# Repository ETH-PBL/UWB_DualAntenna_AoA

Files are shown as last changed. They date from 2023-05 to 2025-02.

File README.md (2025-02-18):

<!--
*** Template source: https://github.com/othneildrew/Best-README-Template/blob/master/README.md
-->

<!-- PROJECT SHIELDS -->
<!--
*** I'm using markdown "reference style" links for readability.
*** Reference links are enclosed in brackets [ ] instead of parentheses ( ).
*** See the bottom of this document for the declaration of the reference variables
*** for contributors-url, forks-url, etc. This is an optional, concise syntax you may use.
*** https://www.markdownguide.org/basic-syntax/#reference-style-links
-->
[][contributors-url]
[][forks-url]
[][stars-url]
[][issues-url]
[][license-url]

# Angle of Arrival and Centimeter Distance Estimation with a miniaturized UWB Module

This repository contains the hardware of an UWB-AoA shield using the Qorvo DW3220 and presented in ***Angle of arrival and centimeter distance estimation on a smart UWB sensor node***. 
Additionally the repository contains firmware to use the module with an STM32 and dataset as presented in the publication. An in-depth analysis of  the hardware and the proposed algorithms for error compensation and angle estimation can be found here: 
[IEEE TIM](https://doi.org/10.1109/TIM.2023.3282289) / [arXiv:2312.13672 (preprint)](https://doi.org/10.48550/arXiv.2312.13672)

> <div align="justify">Accurate and low-power indoor localization is becoming more and more of a necessity to empower novel consumer and industrial applications. In this field, the most promising technology is based on UWB modulation; however, current UWB positioning systems do not reach centimeter accuracy in general deployments due to multipath and nonisotropic antennas, still necessitating several fixed anchors to estimate an object's position in space. This article presents an in-depth study and assessment of angle of arrival (AoA) UWB measurements using a compact, low-power solution integrating a novel commercial module with phase difference of arrival (PDoA) estimation as integrated feature. Results demonstrate the possibility of reaching centimeter distance precision and 2.4° average angular accuracy in many operative conditions, e.g., in a 90° range around the center. Moreover, integrating the channel impulse response, the phase differential of arrival, and the point-to-point distance, an error correction model is discussed to compensate for reflections, multipaths, and front-back ambiguity.</div>

If you use **Angle of Arrival and Centimeter Distance Estimation with a miniaturized UWB Module** in an academic or industrial context, please cite the following publications:

```bibtex
@article{margiani2023angle,
  title={Angle of arrival and centimeter distance estimation on a smart UWB sensor node},
  author={Margiani, Tobias and Cortesi, Silvano and Keller, Milena and Vogt, Christian and Polonelli, Tommaso and Magno, Michele},
  journal={IEEE Transactions on Instrumentation and Measurement},
  doi={https://doi.org/10.1109/TIM.2023.3282289},
  year={2023},
  publisher={IEEE}
}
```

```bibtex
@inproceedings{polonelli2022performance,
  title={Performance Comparison between Decawave DW1000 and DW3000 in low-power double side ranging applications},
  author={Polonelli, Tommaso and Schl{\"a}pfer, Simon and Magno, Michele},
  booktitle={2022 IEEE Sensors Applications Symposium (SAS)},
  doi={https://doi.org/10.1109/SAS54819.2022.9881375},
  pages={1--6},
  year={2022},
  organization={IEEE}
}
```
## Folder structure

The hardware design files are located in [Hardware](Hardware).

The published data and ML models are available in the [Dataset](Dataset) subfolder.

The firmware used for the double antenna and single antenna modules is
available in the [Firmware](Firmware) subfolder.

Each folder contains a `README.md` containing more information.

### Hardware - UWB Modules

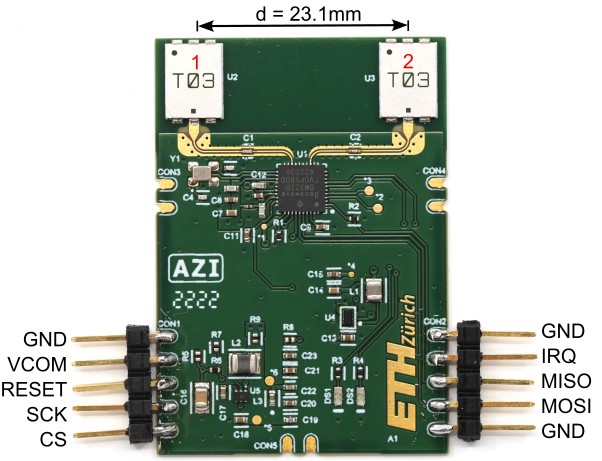
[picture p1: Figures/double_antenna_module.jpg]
Double Antenna Module


We release two modules,
- [T_Module](Hardware/T_module) (22x28 mm) optimized for production cost and dimensions
- [UWB_AoA_module](Hardware/UWB_AoA_module) (30x45 mm) optimized for performances and R&D
   Used for the scientific publication "Angle of arrival and centimeter distance estimation on a smart UWB sensor node"

### Firmware

The firmware consists of basic applications using the Qorvo SDK on an STM32. The created applications read PDoA and CIR values from the UWB module, and transmit them to the computer using UART.

### Dataset

The data contains records from more than 19000 Two Way Ranging (TWR) exchanges
and is collected at the double antenna module. Raw data containing
measurements from each received UWB frame as well as preprocessed data with a
subset of fields from TWR result frames is provided. The training script of two different lightweight ML models is also provided. 

### Scripts

The double antenna UWB module sends measurement data over the serial connection for processing. The scripts in this directory help to save and preprocess that data for analysis.

[contributors-shield]: https://img.shields.io/github/contributors/ETH-PBL/UWB_DualAntenna_AoA.svg?style=flat-square
[contributors-url]: https://github.com/ETH-PBL/UWB_DualAntenna_AoA/graphs/contributors
[forks-shield]: https://img.shields.io/github/forks/ETH-PBL/UWB_DualAntenna_AoA.svg?style=flat-square
[forks-url]: https://github.com/ETH-PBL/UWB_DualAntenna_AoA/network/members
[stars-shield]: https://img.shields.io/github/stars/ETH-PBL/UWB_DualAntenna_AoA.svg?style=flat-square
[stars-url]: https://github.com/ETH-PBL/UWB_DualAntenna_AoA/stargazers
[issues-shield]: https://img.shields.io/github/issues/ETH-PBL/UWB_DualAntenna_AoA.svg?style=flat-square
[issues-url]: https://github.com/ETH-PBL/UWB_DualAntenna_AoA/issues
[license-shield]: https://img.shields.io/github/license/ETH-PBL/UWB_DualAntenna_AoA.svg?style=flat-square
[license-url]: https://github.com/ETH-PBL/UWB_DualAntenna_AoA/blob/master/LICENSE

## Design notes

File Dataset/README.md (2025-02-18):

# Measurement Data

This folder contains two sets of measurement data. First, a dataset to
evaluate the performance of the DW3220 at different distances and roations
("rotation" dataset) and second, a dataset to evaluate the stability of the
measurements over time ("stability" dataset).

## Data collection setup

For all measurements one single antenna module and one double antenna module
was set up in an 8.6m x 7.7m room containing tables and office equipment
placed along the walls and a 6.5m x 5.5m empty space where the measurements
were performed. The single antenna module was fixed on a tripod at a height of
1.1m. The double antenna module was mounted on a rotatable motorized platform
at the same height, providing the ground truth AoA.

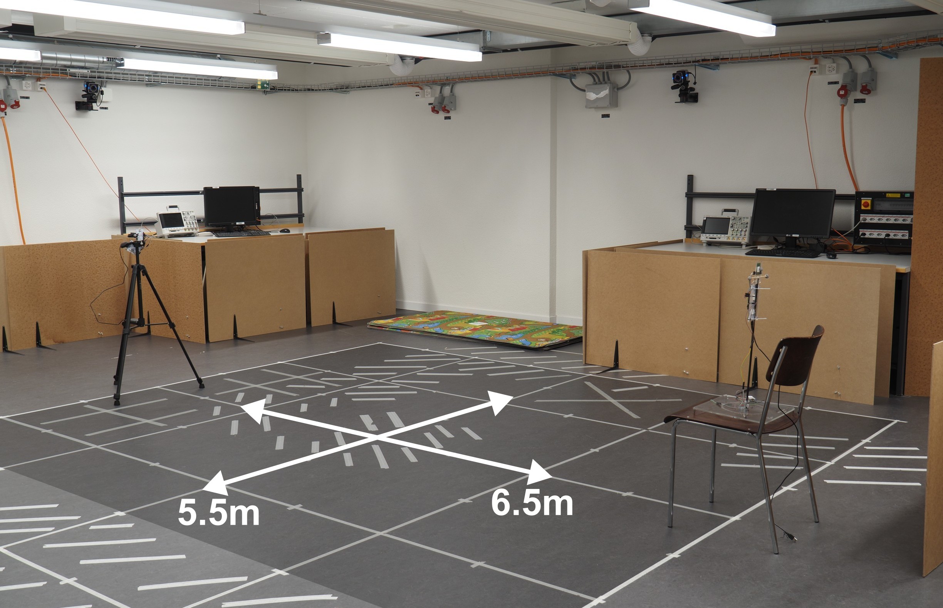
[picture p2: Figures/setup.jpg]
Recording Setup


### Rotation dataset

Data collected at 11 fixed distances ranging from 50cm to 5.5m in 50cm
steps. At each distance, the double antenna module was automatically rotated
in 1 degree steps for a full rotation. At least five TWR measurements were
performed in each position/rotation. Each measurement run contains data for a
single distance and all rotations.

### Stability dataset

Data collected at a fixed distance of 5.4m and with 0, 90, 180, and 270 degree
AoA. Approximately 3000 frames are collected over a period of 11 minutes with
no movement in the room. Each measurement run contains data at a fixed
distance and rotation.

## Data format

The data provided in the two subfolders is based on the same
measurements. First the raw measurements and second a more directly usable
preprocessed HDF datastore containing a subset of the data. For a detailed
description check the README in the respective folders.

| Folder | Data available | Format | Difficulty to use |
|---|---|---|---|
| Raw Measurement Logs | All | Compressed text files | medium to hard |
| Preprocessed Measurement Data | Subset | HDF5 Store | low |

## ML Evaluation

We release in this folder two Jupyter Notebooks with two examples used to train and evaluate a decision tree and a MLP model. Input files are 

```
Dataset/Preprocessed Measurement Data/processed_data_cache_rotation.h5
Dataset/Preprocessed Measurement Data/cache_config_rotation.csv
```

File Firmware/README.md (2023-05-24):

# Firmware

STM32 firmware used for single and double antenna modules. Sources for each
device and usage can be found in the `Core/Src/apps/` folder.

To use, the appropriate application has to be selected (uncommented) in
`Core/Src/apps/applications.h`. For the double antenna module this will be
`APPLICATION_TWR_PDOA_TAG`, for the single antenna module
`APPLICATION_TWR_ANCHOR`. Other applications are for testing purposes.

Additionally, the Qorvo driver package version 04.00.00 has to be added to the
`Drivers/dwt_uwb_driver` folder (required files: `deca_device_api.h`,
`deca_device.c`, `deca_regs.h`, `deca_types.h`, `deca_vals.h`,
`deca_version.h`).

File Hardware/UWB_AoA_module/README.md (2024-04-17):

<!--
*** Template source: https://github.com/othneildrew/Best-README-Template/blob/master/README.md
-->

<!-- PROJECT SHIELDS -->
<!--
*** I'm using markdown "reference style" links for readability.
*** Reference links are enclosed in brackets [ ] instead of parentheses ( ).
*** See the bottom of this document for the declaration of the reference variables
*** for contributors-url, forks-url, etc. This is an optional, concise syntax you may use.
*** https://www.markdownguide.org/basic-syntax/#reference-style-links
-->
[][contributors-url]
[][forks-url]
[][stars-url]
[][issues-url]
[][license-url]

# UWB AoA module
> Note: This repository is currently under construction

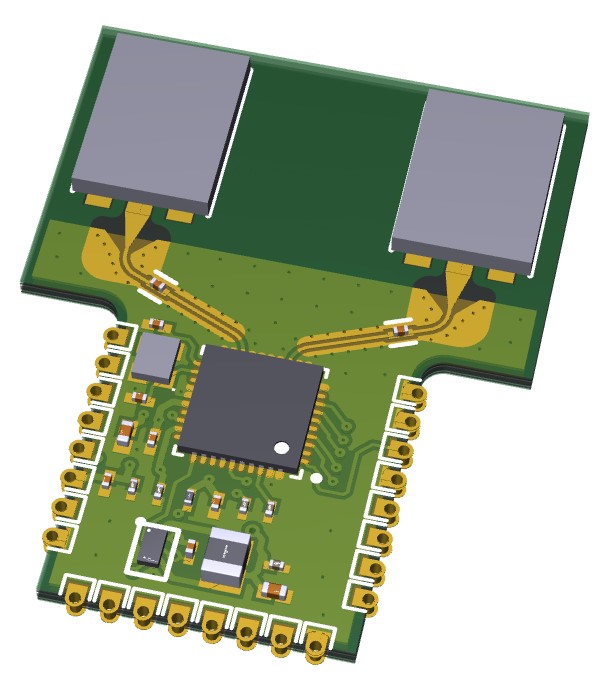
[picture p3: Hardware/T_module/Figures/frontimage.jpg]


## About The Module
The T-Module is a miniaturized UWB module capable of AoA incorporating the DW3220 transceiver and two UWB chip antennas. Thanks to the pin compatibility with the [DWM3000](https://www.qorvo.com/products/p/DWM3000) by 
Qorvo it can be used for existing projects. Information about the functionality of the pins and the footprint can be found in the DWM3000 Datasheet.

### Size
To have enough space for the two antennas the top part of the T-Module is a bit wider than the bottom, giving this T-shape look. The figure below is the shape and placement of the chip antennas of the T-Module overlayed by the DWM3000(hatched).
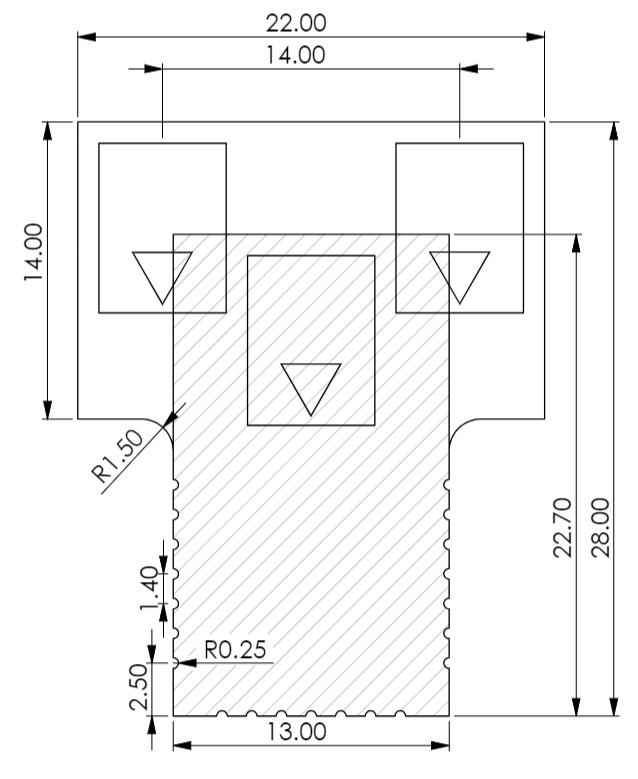
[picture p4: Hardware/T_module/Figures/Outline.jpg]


### Stack Up
For the stack-up depicted below an FR-4 Tg150 dielectric was used.

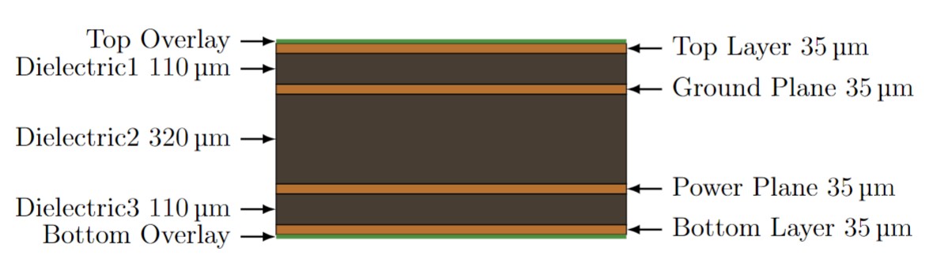
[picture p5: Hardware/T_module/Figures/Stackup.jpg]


[contributors-shield]: https://img.shields.io/github/contributors/ETH-PBL/UWB_DualAntenna_AoA.svg?style=flat-square
[contributors-url]: https://github.com/ETH-PBL/UWB_DualAntenna_AoA/graphs/contributors
[forks-shield]: https://img.shields.io/github/forks/ETH-PBL/UWB_DualAntenna_AoA.svg?style=flat-square
[forks-url]: https://github.com/ETH-PBL/UWB_DualAntenna_AoA/network/members
[stars-shield]: https://img.shields.io/github/stars/ETH-PBL/UWB_DualAntenna_AoA.svg?style=flat-square
[stars-url]: https://github.com/ETH-PBL/UWB_DualAntenna_AoA/stargazers
[issues-shield]: https://img.shields.io/github/issues/ETH-PBL/UWB_DualAntenna_AoA.svg?style=flat-square
[issues-url]: https://github.com/ETH-PBL/UWB_DualAntenna_AoA/issues
[license-shield]: https://img.shields.io/github/license/ETH-PBL/UWB_DualAntenna_AoA.svg?style=flat-square
[license-url]: https://github.com/ETH-PBL/UWB_DualAntenna_AoA/blob/master/LICENSE

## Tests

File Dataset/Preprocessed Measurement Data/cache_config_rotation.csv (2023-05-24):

title | filename | description
50cm | ../Raw Measurement Logs/rotation_50cm.log.gz | Distance 50cm, one full turn, 5 samples per 1 degree rotation step, LOS
100cm | ../Raw Measurement Logs/rotation_100cm.log.gz | Distance 100cm, one full turn, 5 samples per 1 degree rotation step, LOS
150cm | ../Raw Measurement Logs/rotation_150cm.log.gz | Distance 150cm, one full turn, 5 samples per 1 degree rotation step, LOS
200cm | ../Raw Measurement Logs/rotation_200cm.log.gz | Distance 200cm, one full turn, 5 samples per 1 degree rotation step, LOS
250cm | ../Raw Measurement Logs/rotation_250cm.log.gz | Distance 250cm, one full turn, 5 samples per 1 degree rotation step, LOS
300cm | ../Raw Measurement Logs/rotation_300cm.log.gz | Distance 300cm, one full turn, 5 samples per 1 degree rotation step, LOS
350cm | ../Raw Measurement Logs/rotation_350cm.log.gz | Distance 350cm, one full turn, 5 samples per 1 degree rotation step, LOS
400cm | ../Raw Measurement Logs/rotation_400cm.log.gz | Distance 400cm, one full turn, 5 samples per 1 degree rotation step, LOS
450cm | ../Raw Measurement Logs/rotation_450cm.log.gz | Distance 450cm, one full turn, 5 samples per 1 degree rotation step, LOS
500cm | ../Raw Measurement Logs/rotation_500cm.log.gz | Distance 500cm, one full turn, 5 samples per 1 degree rotation step, LOS
550cm | ../Raw Measurement Logs/rotation_550cm.log.gz | Distance 550cm, one full turn, 5 samples per 1 degree rotation step, LOS

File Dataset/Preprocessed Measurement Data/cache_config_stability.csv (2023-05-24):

title | filename | description
90deg | ../Raw Measurement Logs/stability_90deg.log.gz | Distance 5.4m, no rotation (fixed 90deg AoA), approx 3000 frames, no movement in the room, LOS
270deg | ../Raw Measurement Logs/stability_270deg.log.gz | Distance 5.4m, no rotation (fixed 270deg AoA), approx 3000 frames, no movement in the room, LOS
0deg | ../Raw Measurement Logs/stability_0deg.log.gz | Distance 5.4m, no rotation (fixed 0deg AoA), approx 3000 frames, no movement in the room, LOS
180deg | ../Raw Measurement Logs/stability_180deg.log.gz | Distance 5.4m, no rotation (fixed 180deg AoA), approx 3000 frames, no movement in the room, LOS

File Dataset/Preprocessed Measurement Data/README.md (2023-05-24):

# Preprocessed Measurement Data

To reduce the time and memory requirements and to efficiently access the
relevant measurement data it can be preprocessed and stored into a single HDF5
file. This is automated by the `../Scripts/parse_and_cache.py` script,
requiring a csv configuration file.

A [Jupyter](https://jupyter.org/) notebook is provided (`data reading
example.ipynb`) outlining how to use the HDF5 file with the
[Pandas](https://pandas.pydata.org/) library.

Configuration files are provided for rotation and stability datasets. Each
takes all measurement runs from one dataset and combines them into a single
HDF store. The configuration file format is CSV with one header line followed
by one line for each measurement run. Each line contains the fileds:

| Name | Description |
|---|---|
| `title` | Short identifier of the measurement run |
| `filename` | The filename of the compressed or uncompressed raw measurement log |
| `description` | Short description of the measurement run |

The HDF5 store will then contain two tables per measurement run with the names
`/cache_[title]/info` and `/cache_[title]/df` (replacing `[title]` with the
title as given in the configuration file). The first containing the
configuration information, as well as a timestamp and version number, while
the latter contains the measurement data. In version 4 of the cache file (as
provided here) the following fields are included:

| Name | Description |
|---|---|
| `timestamp` | Timestamp (s) of data collection relative to the start |
| `number` | TWR frame counter |
| `rotation` | Ground truth rotation value (deg), values above 359 should be considered module 360 |
| `pdoa` | Phase Difference of Arrival (rad) |
| `tdoa` | Time Difference of Arrival (15.65ps) |
| `dist_mm` | TWR distance estimate (mm) |
| `rx_power_level` | Received signal power level (computed according to DW3000 family user manual section 4.7) |
| `fp_power_level` | First path power level (computed according to DW3000 family user manual section 4.7) |
| `cir_sts1` | Channel Impulse Response at first antenna (105 samples) |
| `cir_sts2` | Channel Impulse Response at second antenna (105 samples) |

To recreate these HDF stores the following commands can be used:

```
../../Scripts/parse_and_cache.py -i cache_config_rotation.csv processed_data_cache_rotation.h5
../../Scripts/parse_and_cache.py -i cache_config_stability.csv processed_data_cache_stability.h5
```

For more details on how to change the data fields have a look at the comments
in the script.

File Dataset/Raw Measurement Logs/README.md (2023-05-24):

# Raw measurement logs from the double antenna UWB module

This folder contains the raw measurement logs from the double antenna UWB
module. It contains all data collected by the module for each UWB frame
received while performing two way ranging (TWR).

Each file name starts with the name of the dataset, i.e. "rotation" or
"stability", followed by an identifier of the specific setup. For the rotation
dataset this is the distance between the two modules in cm, while for the
stability dataset it is the AoA in degrees. For example the file
`rotation_150cm.log.gz` contains one measurement run of the rotation setup at
a distance of 1.5m, while the file `stability_180deg.log.gz` contains one
measurement run of the stability dataset at 180 deg AoA.

Each gzip compressed log file contains a text file with the measurement
results (same filename, except without the ".gz"). Each line in the log file
contains either human readable metadata or a base64 encoded binary measurement
blob. Each human readable line starts with a timestamp in seconds
(e.g. `0010.87627`), while the data lines start with (`XXXX.XXXXX`) and are
always preceded by by a line containing information about the data blob.

The binary data contains a C struct with measurements which can be read by the
scripts provided in the `../Scripts` forlder. For details on the data format
check the `binary_reader.py` script. For analysing the data it is suggested to
use the `parse_and_cache.py` script to generate a HDF5 file containing only
the data fields of interest, greatly improving memory and time requirements of
further processing.

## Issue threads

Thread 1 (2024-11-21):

UWB_AoA_module Gerber are not clear

sauravpanchal369, 2024-11-21:
Hi, Provided Gerber files have issues with plane in layer GP1 and GP2. There should be copper in middle of board which seems like bank
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

Is the shown plane is correct ??
if not please provide correct gerber files..
Thanks

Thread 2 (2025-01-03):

dist_mm in Dataframes are very large numbers?

AethM, 2025-01-03:
Hello, I'm currently figuring out the dataframes format, thanks for the clear explanation in those README.md's! However, I can't seem to find any words explaining why the data in column "dist_mm" are mostly very big numbers (eg. 7132146), with 26 or 40 rarely appearing. Is this normal? Or does the large numbers mean UWB has not measured the distance yet so they send these large numbers as invalid values? Thanks in advance!

MarcusLariJ, 2025-06-18:
Very late answer, but I have spent the last 5 months working with this node, and it is due to two factors:
- The transmission delays are very large and not equal for tag and anchor. Ideally, they should be below 1 ms to minimize the effect of clock drift, but in their firmware it is 100 ms for the tag and 10 ms for the anchor. This throws the distance readings off and makes them drift heavily over time (see the Qorvo application note on errors in DS TWR).
- The nodes have not been calibrated for antenna delay (se the Qorvo application notes on achieving accuracy with DS TWR). This calibration should be able to be done offline though, as it just adds an offset to the time stamps.
Fixing these two issues in the firmware allows for much more accurate readings.

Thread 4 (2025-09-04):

Question about Board Configuration and Ranging Setup

haru9711, 2025-09-04:
Hello, I have assembled the board using the hardware source files that you published on GitHub and successfully flashed the firmware onto the MCU. After configuring all settings as instructed, I tested the provided examples for RX and TX on separate boards.

When I set the single-antenna board as TX and performed RX on the same board, I was able to receive messages successfully. However, when I configured the single-antenna board as RX and attempted to perform TX on the same board, it did not work as expected.

Could you please confirm whether I may have performed the test incorrectly, or if there is a different procedure required in this case? Additionally, I would greatly appreciate it if you could share how you configured the board and which specific setup you used to perform ranging successfully during your development.

Thank you very much for your support.

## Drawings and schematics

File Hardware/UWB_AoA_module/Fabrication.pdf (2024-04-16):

## View from Top side (Scale 4:1)

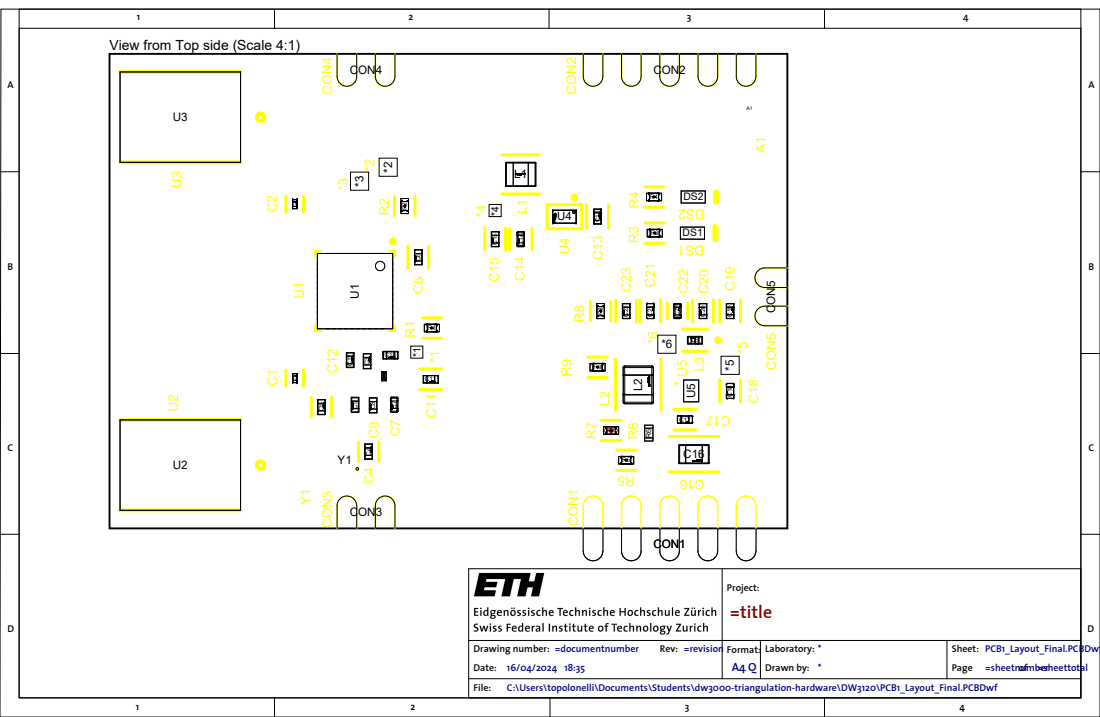
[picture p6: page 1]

Sheet:
Page =sheetnumber of =sheettotal

C:\Users\topolonelli\Documents\Students\dw3000-triangulation-hardware\DW3120\PCB1_Layout_Final.PCBDwf

| Project: =title
Drawing number: =documentnumber Rev: =revision | Format: | Laboratory: * | Sheet:
PCB1_Layout_Final.PCBDwf

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
Line # | Designator | Comment | Quantity
1 | C1, C2 | GJM0335C1E2R0WB01D | 2
2 | C3 | GRM155R71C224KA12D | 1
3 | C4, C5 | GJM1555C1H3R3BB01D | 2
4 | C6, C8, C11, C15, C20, C23 | GRM155R71E104ME14D | 6
5 | C7, C14 | GRM155R60J106ME47D | 2
6 | C9, C10, C12 | GRM1555C1H472GE01D | 3
7 | C13 | GRM155C80J475MEAAD | 1
8 | C16 | GRM21BR60J107ME15L | 1
9 | C17, C18, C21 | GRM155R60J475ME47D | 3
10 | C19 | GRM1555C1H102JA01D | 1
11 | C22 | CC0402KRX7R7BB103 | 1
12 | CON1, CON2 | Con_Pad | 2
13 | CON3, CON4, CON5 | Con_Pad_GND | 3
14 | DS1 | TLMS1100-GS08 | 1
15 | DS2 | TLMY1100-GS08 | 1
16 | FB1 | MPZ0603S330HT000 | 1
17 | L1 | 1285AS-H-2R2M=P2 | 1
18 | L2 | LQM2HPN1R0MJ0L | 1
19 | L3 | LQG15HS3N6B02D | 1
20 | R1, R2, R3, R4 | CRCW0402100KFKED, [NoValue] | 4
21 | R5, R8, R9 | CRCW04020000Z0ED | 3
22 | R6 | CPF0402B47K5E1 | 1
23 | U1 | DW3220 | 1
24 | U2, U3 | AH086M555003-T | 2
25 | U4 | TPS62743YFPR | 1
26 | U5 | TPS62233DRYR | 1
27 | Y1 | 8Y38472012 | 1

## Bill Of Materials

Material | Layer | Thickness Dielectric Material Type | Gerber
| Top Overlay | Legend | GTO

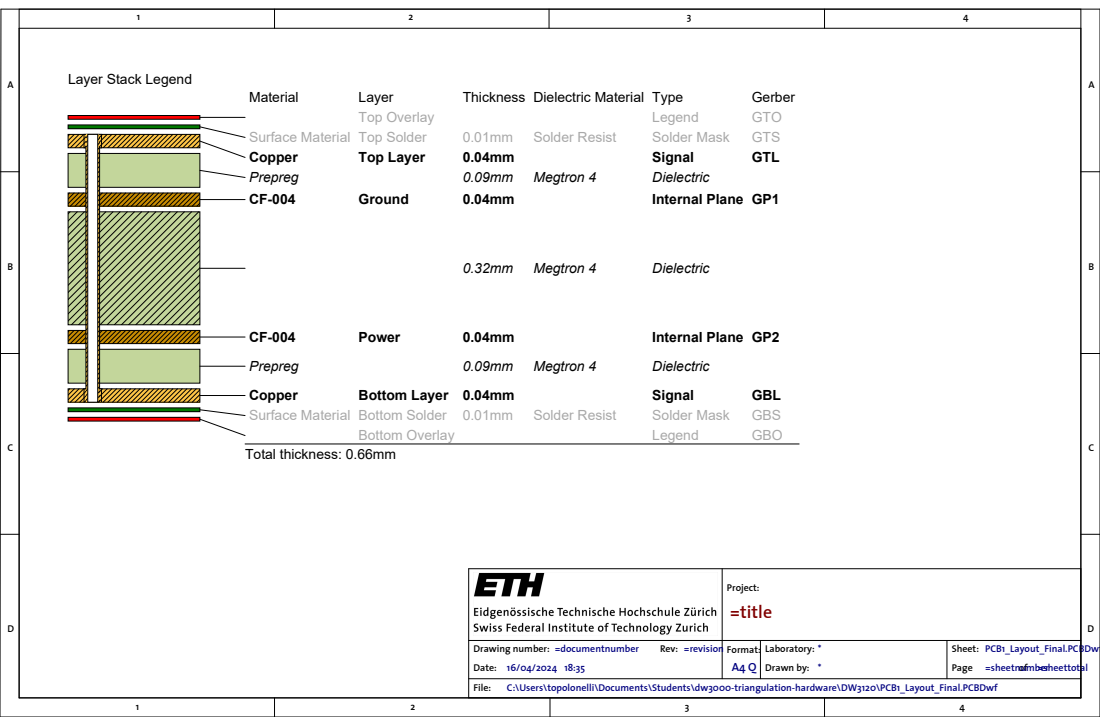
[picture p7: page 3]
PCB1_Layout_Final.PCBDwf; Surface Material Top Solder; Solder Resist; Solder Mask; GTS; Copper; Top Layer; Signal; GTL; Prepreg; Megtron 4; Dielectric; Ground; Internal Plane GP1; Power; Internal Plane GP2; Bottom Layer 0.04mm; GBL; Surface Material Bottom Solder 0.01mm; GBS; Bottom Overlay; Legend; GBO; Total thickness: 0.66mm

Layer Stack Legend

Project: =title

Drawing number: =documentnumber Rev: =revision | Format: | Laboratory: * | Sheet:

Top Layer (Scale 1:1) | Ground (Scale 1:1) | Power (Scale 1:1) | Bottom Layer (Scale 1:1)

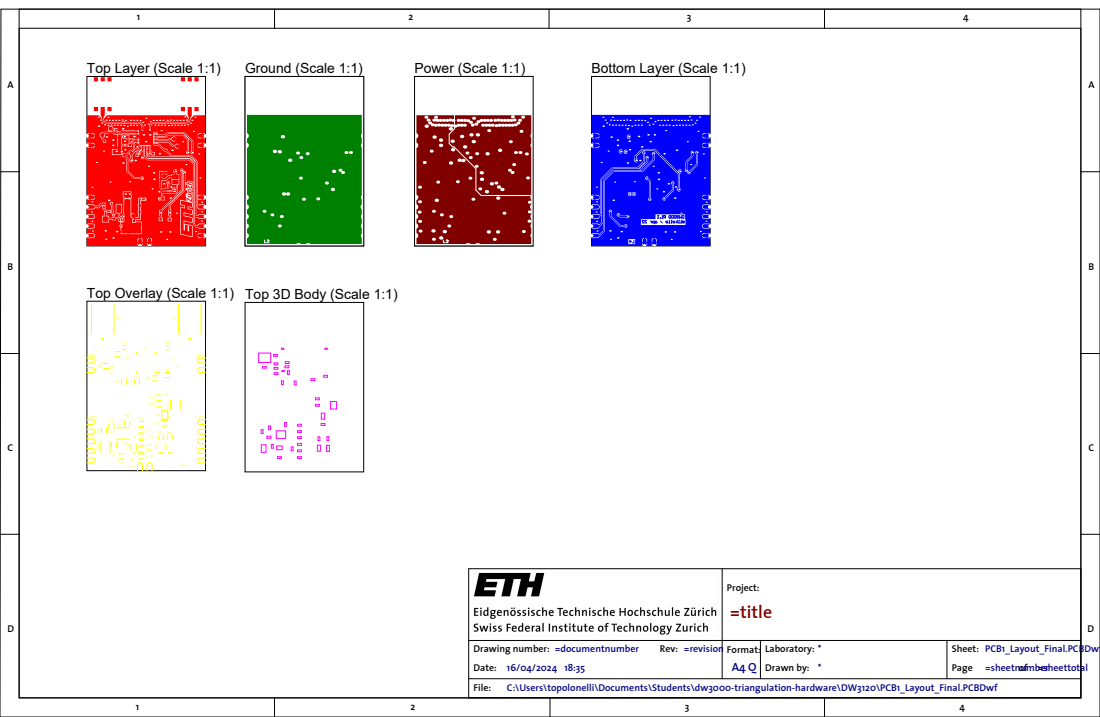
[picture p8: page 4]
PCB1_Layout_Final.PCBDwf

Top Overlay (Scale 1:1) Top 3D Body (Scale 1:1)

Project: =title

Drawing number: =documentnumber Rev: =revision | Format: | Laboratory: * | Sheet:

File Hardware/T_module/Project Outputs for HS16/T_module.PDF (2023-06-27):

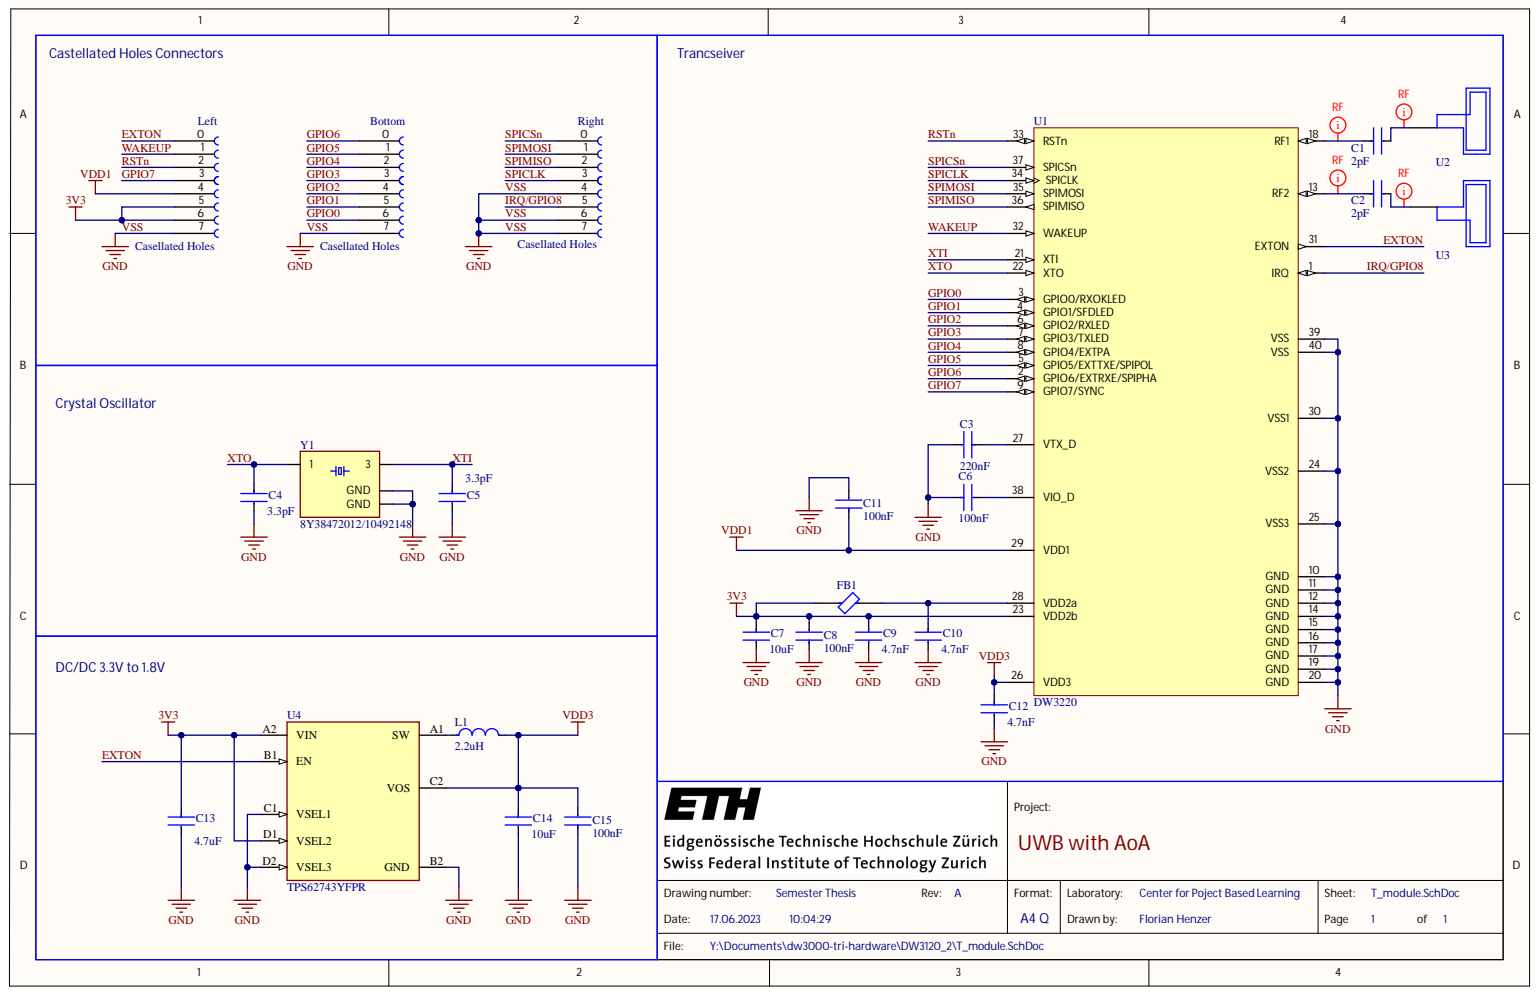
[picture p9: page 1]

EN B1 VSEL1 C1

Project: UWB with AoA

VSEL2 D1

VSEL3 D2

Drawing number: Semester Thesis Rev: A Date: 17.06.2023 10:04:29 | Format: A4 Q | Laboratory: Center for Poject Based Learning Drawn by: Florian Henzer | Sheet: T_module.SchDoc Page 1 of 1

GND | GND

Y:\Documents\dw3000-tri-hardware\DW3120_2\T_module.SchDoc

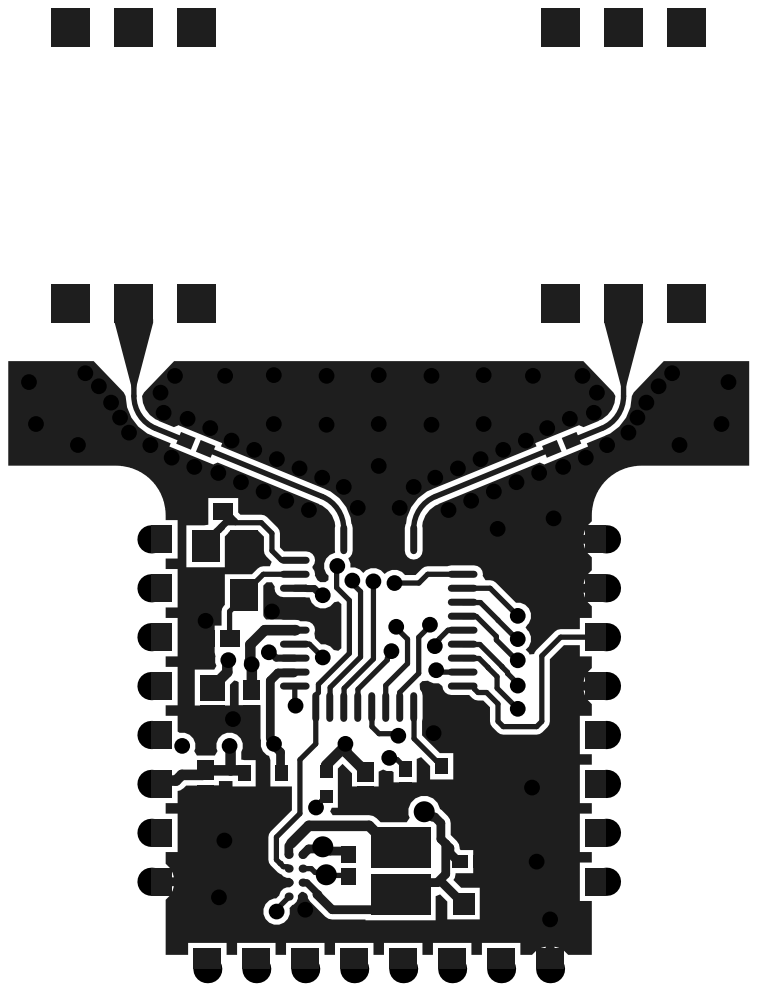
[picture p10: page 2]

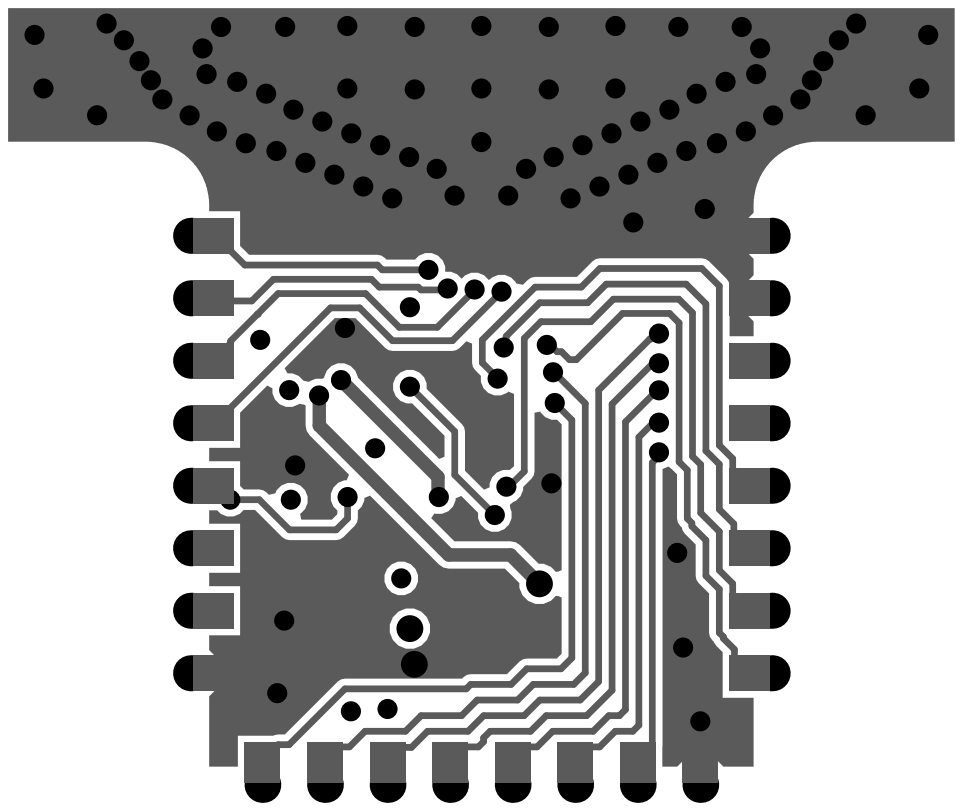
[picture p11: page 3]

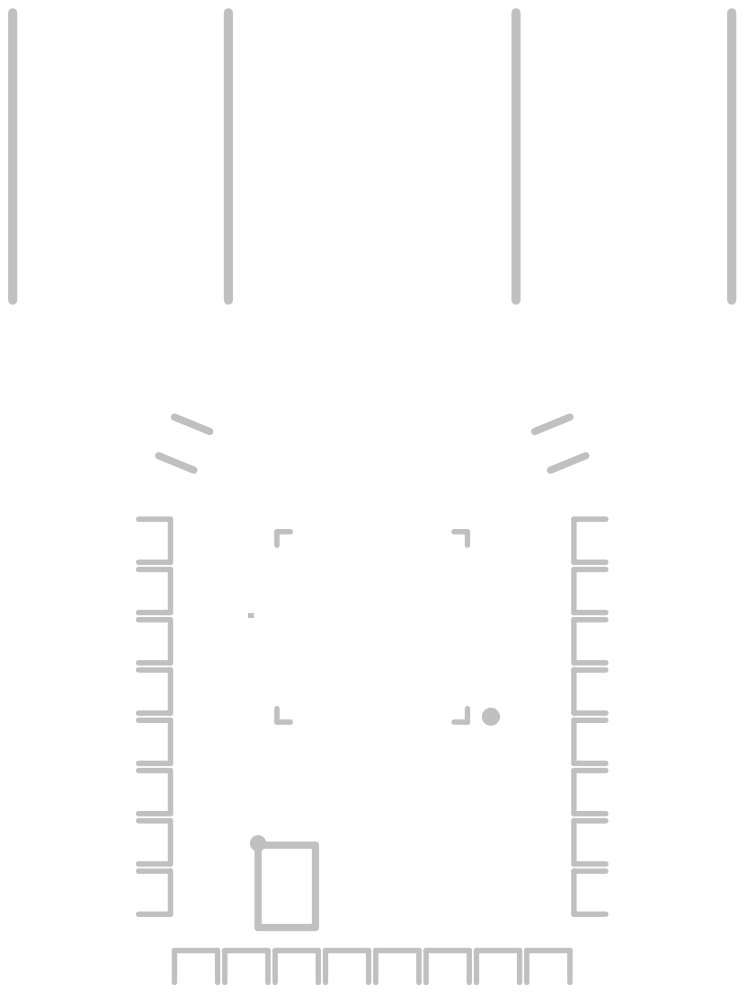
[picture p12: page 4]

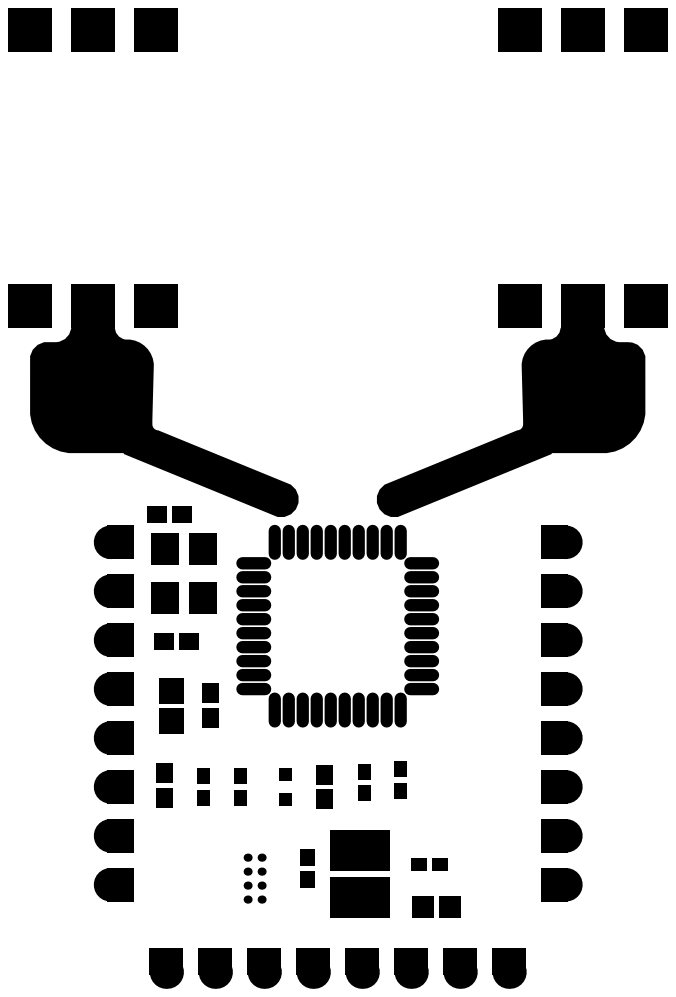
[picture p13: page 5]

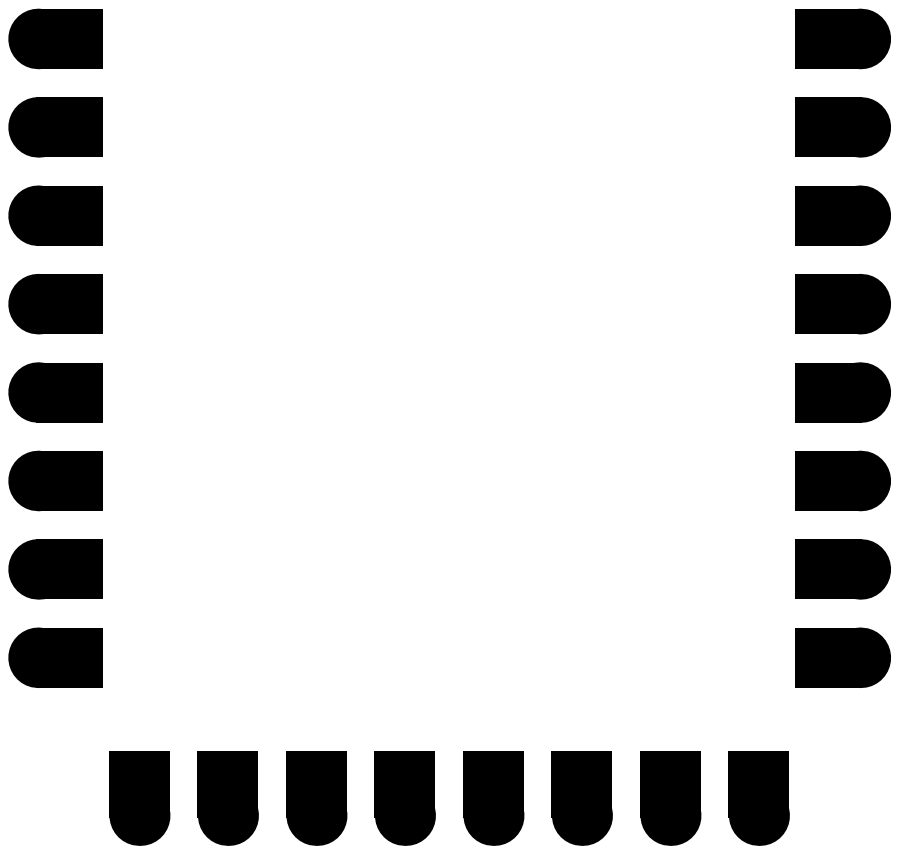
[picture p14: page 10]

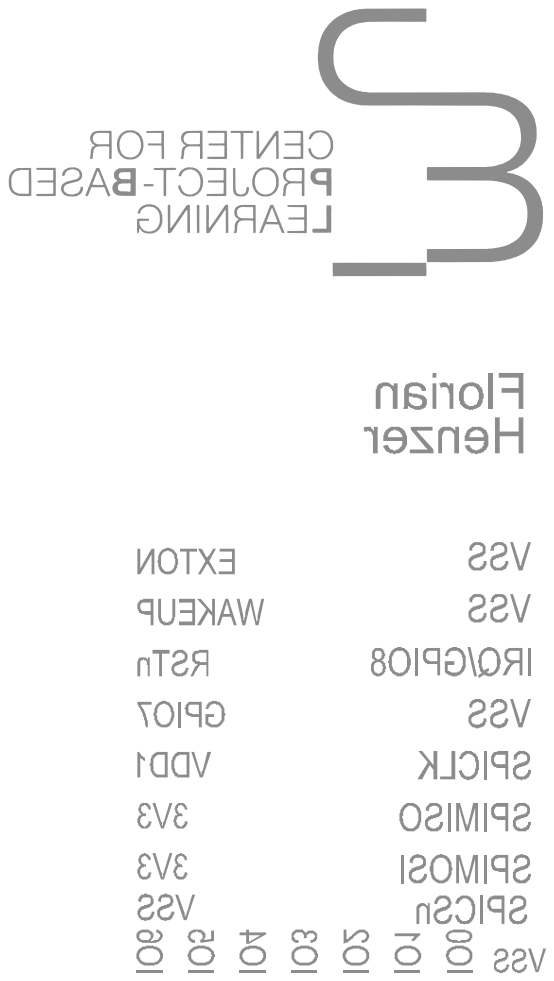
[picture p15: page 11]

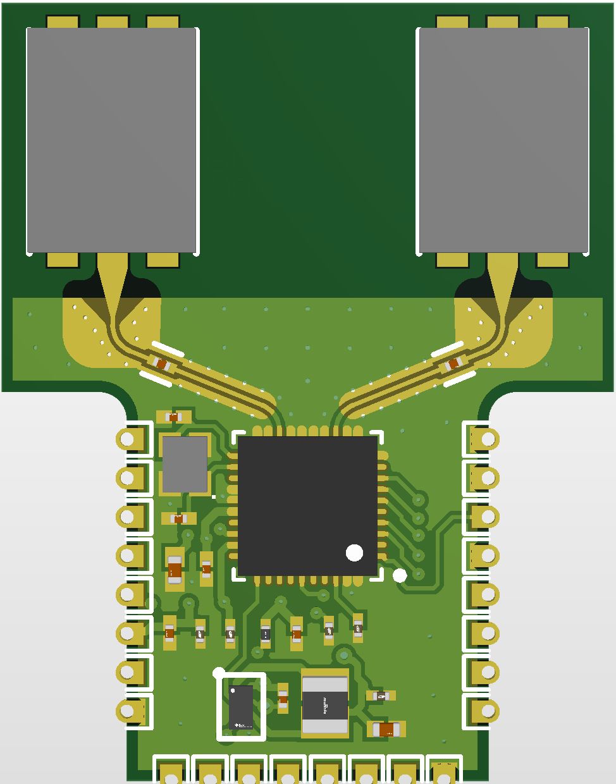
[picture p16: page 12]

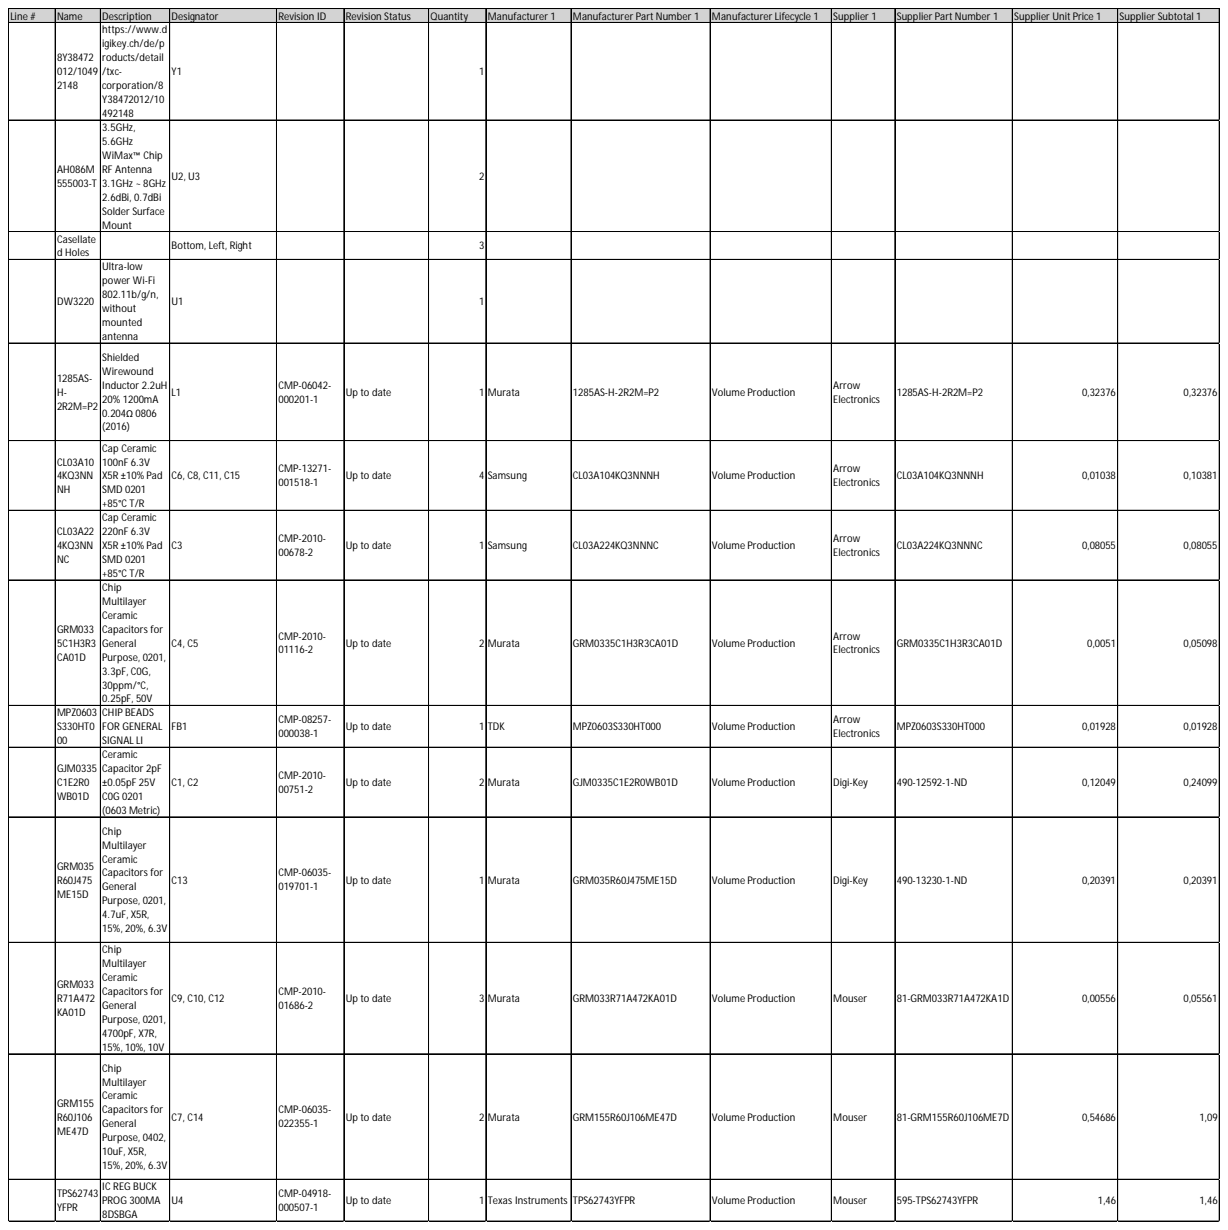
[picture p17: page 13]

Line # | Name | Description | Designator | Revision ID | Revision Status | Quantity | Manufacturer 1 | Manufacturer Part Number 1 | Manufacturer Lifecycle 1 | Supplier 1 | Supplier Part Number 1 | Supplier Unit Price 1 | Supplier Subtotal 1

8Y38472 012/1049 2148 | https://www.digikey.ch/de/products/detail/txc-corporation/8Y38472012/10 492148 | Y1 | | | 1

AH086M 555003-T | 3.5GHz, 5.6GHz WiMax™ Chip RF Antenna 3.1GHz ~ 8GHz 2.6dBi, 0.7dBi Solder Surface Mount | U2, U3 | | | 2

Casellate d Holes | | Bottom, Left, Right | | | 3

DW3220 | Ultra-low power Wi-Fi 802.11b/g/n, without mounted antenna | U1 | | | 1

1285AS-H-2R2M=P2 | Shielded Wirewound Inductor 2.2uH 20% 1200mA 0.204Ω 0806 (2016) | L1 | CMP-06042-000201-1 | Up to date | 1 | Murata | 1285AS-H-2R2M=P2 | Volume Production | Arrow Electronics | 1285AS-H-2R2M=P2 | 0,32376 | 0,32376

CL03A10 4KQ3NN NH | Cap Ceramic 100nF 6.3V X5R ±10% Pad SMD 0201 +85°C T/R | C6, C8, C11, C15 | CMP-13271-001518-1 | Up to date | 4 Samsung | | CL03A104KQ3NNNH | Volume Production | Arrow Electronics | CL03A104KQ3NNNH | 0,01038 | 0,10381

CL03A22 4KQ3NN NC | Cap Ceramic 220nF 6.3V X5R ±10% Pad SMD 0201 +85°C T/R | C3 | CMP-2010-00678-2 | Up to date | 1 | Samsung | CL03A224KQ3NNNC | Volume Production | Arrow Electronics | CL03A224KQ3NNNC | 0,08055 | 0,08055

GRM033 5C1H3R3 CA01D | Chip Multilayer Ceramic Capacitors for General Purpose, 0201, 3.3pF, C0G, 30ppm/°C, 0.25pF, 50V | C4, C5 | CMP-2010-01116-2 | Up to date | 2 Murata | | GRM0335C1H3R3CA01D | Volume Production | Arrow Electronics | GRM0335C1H3R3CA01D | 0,0051 | 0,05098

MPZ0603 S330HT0 00 | CHIP BEADS FOR GENERAL SIGNAL LI | FB1 | CMP-08257-000038-1 | Up to date | 1 | TDK | MPZ0603S330HT000 | Volume Production | Arrow Electronics | MPZ0603S330HT000 | 0,01928 | 0,01928

GJM0335 C1E2R0 WB01D | Ceramic Capacitor 2pF ±0.05pF 25V C0G 0201 (0603 Metric) | C1, C2 | CMP-2010-00751-2 | Up to date | 2 Murata | | GJM0335C1E2R0WB01D | Volume Production | Digi-Key | 490-12592-1-ND | 0,12049 | 0,24099

GRM035 R60J475 ME15D | Chip Multilayer Ceramic Capacitors for General Purpose, 0201, 4.7uF, X5R, 15%, 20%, 6.3V | C13 | CMP-06035-019701-1 | Up to date | 1 | Murata | GRM035R60J475ME15D | Volume Production | Digi-Key | 490-13230-1-ND | 0,20391 | 0,20391

GRM033 R71A472 KA01D | Chip Multilayer Ceramic Capacitors for General Purpose, 0201, 4700pF, X7R, 15%, 10%, 10V | C9, C10, C12 | CMP-2010-01686-2 | Up to date | 3 Murata | | GRM033R71A472KA01D | Volume Production | Mouser | 81-GRM033R71A472KA1D | 0,00556 | 0,05561

GRM155 R60J106 ME47D | Chip Multilayer Ceramic Capacitors for General Purpose, 0402, 10uF, X5R, 15%, 20%, 6.3V | C7, C14 | CMP-06035-022355-1 | Up to date | 2 Murata | | GRM155R60J106ME47D | Volume Production | Mouser | 81-GRM155R60J106ME7D | 0,54686 | 1,09

TPS62743 YFPR | IC REG BUCK PROG 300MA 8DSBGA | U4 | CMP-04918-000507-1 | Up to date | 1 | Texas Instruments | TPS62743YFPR | Volume Production | Mouser | 595-TPS62743YFPR | 1,46 | 1,46

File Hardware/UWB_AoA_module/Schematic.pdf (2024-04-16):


ETHZurich Logo ETH Zurich

Project: TOF_Deck

Drawing number: Master Project. Rev: A Date: 16/04/2024 18:34:55 | Format: A4 Q | Laboratory: PBL Drawn by: Iman Ostovar | Sheet: Deck.SchDoc Page 1 of 2

C:\Users\topolonelli\Documents\Students\dw3000-triangulation-hardware\DW3120\Deck.SchDoc


VDD2a 28 VDD2b 23

VDD3 26

EN B1 VSEL1 C1



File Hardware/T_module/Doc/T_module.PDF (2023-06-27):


EN B1 VSEL1 C1

Project: UWB with AoA

VSEL2 D1

VSEL3 D2

Drawing number: Semester Thesis Rev: A Date: 17.06.2023 10:00:13 | Format: A4 Q | Laboratory: Center for Poject Based Learning Drawn by: Florian Henzer | Sheet: T_module.SchDoc Page 1 of 1

Y:\Documents\dw3000-tri-hardware\DW3120_2\T_module.SchDoc

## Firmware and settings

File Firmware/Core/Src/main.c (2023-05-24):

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
/* Includes ------------------------------------------------------------------*/
#include "main.h"

/* USER CODE BEGIN Includes */
#include "port.h"
#include "uart_stdio.h"
#include "apps/applications.h"
/* USER CODE END Includes */

 SPI_HandleTypeDef hspi5;

UART_HandleTypeDef huart3;

void SystemClock_Config(void);
static void MX_GPIO_Init(void);
static void MX_USART3_UART_Init(void);
static void MX_SPI5_Init(void);
/**
  * @brief  The application entry point.
  * @retval int
  */
int main(void)
{
  /* MCU Configuration--------------------------------------------------------*/

  /* Reset of all peripherals, Initializes the Flash interface and the Systick. */
  HAL_Init();

  /* Configure the system clock */
  SystemClock_Config();

  /* Initialize all configured peripherals */
  MX_GPIO_Init();
  MX_USART3_UART_Init();
  MX_SPI5_Init();
  /* USER CODE BEGIN 2 */

  /* ----- Setup DW3000, USART and start main application ----- */

  /* DW3000 will be configured and enabled later, if necessary, but CubeMX has
   * no option to generate code without enabling the interrupt. */
  HAL_NVIC_DisableIRQ(EXTI15_10_IRQn);

  /*
   * DW_RESET_Pin has been configured by CubeMx as Exti0 line
   * Reconfigure the line as Input
   */
  setup_DWICRSTnIRQ(0);

  stdio_init(&huart3);

  dw_main();

  /* USER CODE END 2 */

  /* Infinite loop */
  /* USER CODE BEGIN WHILE */
  while (1)
  {
    /* USER CODE END WHILE */

    /* USER CODE BEGIN 3 */
  }
  /* USER CODE END 3 */
}

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


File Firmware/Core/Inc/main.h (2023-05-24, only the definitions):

#define DW_RESET_Pin GPIO_PIN_3
#define DW_RESET_GPIO_Port GPIOE
#define USER_Btn_Pin GPIO_PIN_13
#define USER_Btn_GPIO_Port GPIOC
#define USER_Btn_EXTI_IRQn EXTI15_10_IRQn
#define MCO_Pin GPIO_PIN_0
#define MCO_GPIO_Port GPIOH
#define MOTOR_DIR_Pin GPIO_PIN_0
#define MOTOR_DIR_GPIO_Port GPIOC
#define RMII_MDC_Pin GPIO_PIN_1
#define RMII_MDC_GPIO_Port GPIOC
#define RMII_REF_CLK_Pin GPIO_PIN_1
#define RMII_REF_CLK_GPIO_Port GPIOA
#define RMII_MDIO_Pin GPIO_PIN_2
#define RMII_MDIO_GPIO_Port GPIOA
#define MOTOR_STEP_Pin GPIO_PIN_3
#define MOTOR_STEP_GPIO_Port GPIOA
#define RMII_RXD0_Pin GPIO_PIN_4
#define RMII_RXD0_GPIO_Port GPIOC
#define RMII_RXD1_Pin GPIO_PIN_5
#define RMII_RXD1_GPIO_Port GPIOC
#define LD1_Pin GPIO_PIN_0
#define LD1_GPIO_Port GPIOB
#define DW_NSS_Pin GPIO_PIN_1
#define DW_NSS_GPIO_Port GPIOG
#define DW_IRQn_Pin GPIO_PIN_12
#define DW_IRQn_GPIO_Port GPIOE
#define DW_IRQn_EXTI_IRQn EXTI15_10_IRQn
#define RMII_TXD1_Pin GPIO_PIN_13
#define RMII_TXD1_GPIO_Port GPIOB
#define LD3_Pin GPIO_PIN_14
#define LD3_GPIO_Port GPIOB
#define STLK_RX_Pin GPIO_PIN_8
#define STLK_RX_GPIO_Port GPIOD
#define STLK_TX_Pin GPIO_PIN_9
#define STLK_TX_GPIO_Port GPIOD
#define USB_PowerSwitchOn_Pin GPIO_PIN_6
#define USB_PowerSwitchOn_GPIO_Port GPIOG
#define USB_OverCurrent_Pin GPIO_PIN_7
#define USB_OverCurrent_GPIO_Port GPIOG
#define USB_SOF_Pin GPIO_PIN_8
#define USB_SOF_GPIO_Port GPIOA
#define USB_VBUS_Pin GPIO_PIN_9
#define USB_VBUS_GPIO_Port GPIOA
#define USB_ID_Pin GPIO_PIN_10
#define USB_ID_GPIO_Port GPIOA
#define USB_DM_Pin GPIO_PIN_11
#define USB_DM_GPIO_Port GPIOA
#define USB_DP_Pin GPIO_PIN_12
#define USB_DP_GPIO_Port GPIOA
#define TMS_Pin GPIO_PIN_13
#define TMS_GPIO_Port GPIOA
#define TCK_Pin GPIO_PIN_14
#define TCK_GPIO_Port GPIOA
#define RMII_TX_EN_Pin GPIO_PIN_11
#define RMII_TX_EN_GPIO_Port GPIOG
#define RMII_TXD0_Pin GPIO_PIN_13
#define RMII_TXD0_GPIO_Port GPIOG
#define LD2_Pin GPIO_PIN_7
#define LD2_GPIO_Port GPIOB
#define STATE_OUT1_Pin GPIO_PIN_8
#define STATE_OUT1_GPIO_Port GPIOB
#define STATE_OUT2_Pin GPIO_PIN_9
#define STATE_OUT2_GPIO_Port GPIOB

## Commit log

2023-05-24 Add preprocessed measurement data
    [cache_config_rotation.csv, cache_config_stability.csv]
2023-05-24 Add STM32 firmware
2023-06-27 Hardware first commit
    [T_module.GBL, T_module.GBO, T_module.GBP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]
2024-04-16 UWB_AoA_module release
    [DW3000.SchDoc, DW3120.PrjPcb, Deck.SchDoc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]

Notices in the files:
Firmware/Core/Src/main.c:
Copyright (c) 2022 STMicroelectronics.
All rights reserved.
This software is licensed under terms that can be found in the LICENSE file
